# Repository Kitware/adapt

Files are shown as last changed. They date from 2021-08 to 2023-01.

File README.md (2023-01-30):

# ADAPT Multi-Mission Payload

### An open source platform for deploying state of the art deep-neural-network computer vision in real time on small unmanned aircraft systems (sUAS).

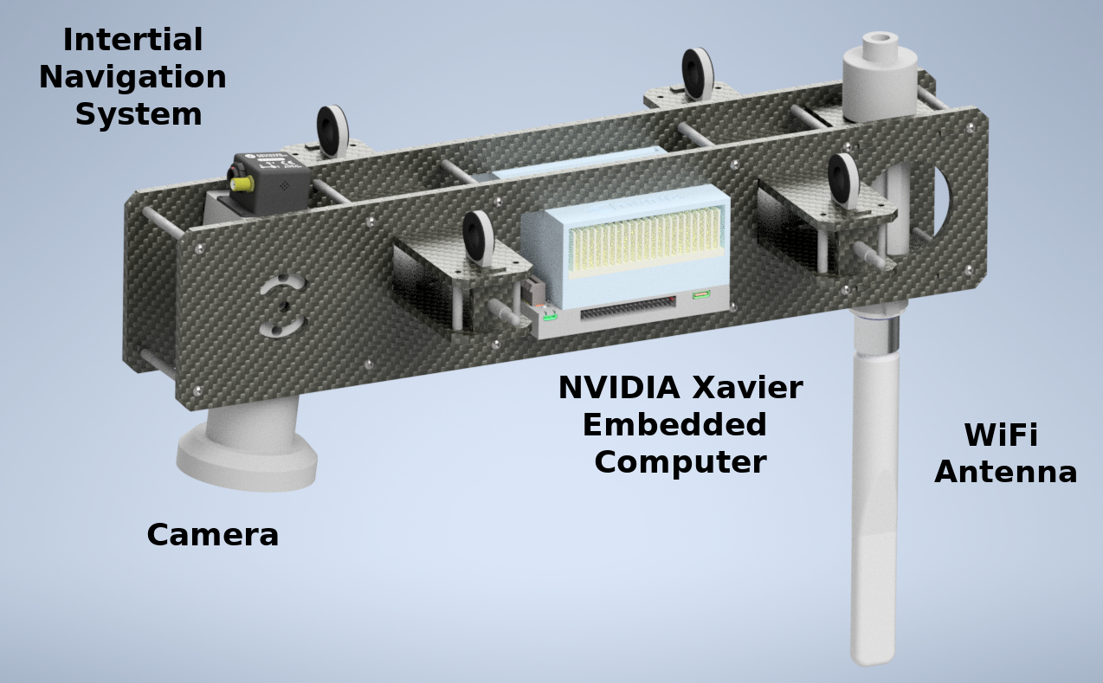
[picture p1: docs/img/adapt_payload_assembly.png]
Payload CAD Rendering

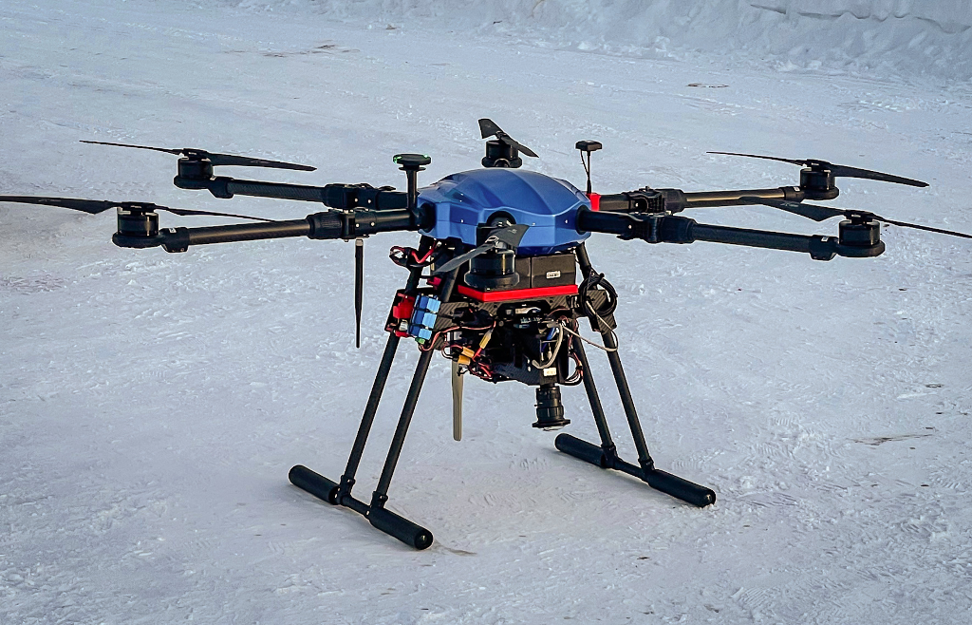
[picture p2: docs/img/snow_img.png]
sUAS


* Optimized drone-based collection of imagery and geospatial metadata with live feedback to maintain quality control.

* Integration with the open source do-it-yourself AI toolkit [VIAME](https://www.viametoolkit.org/) to annotate data and train mission-specific image-processing models.

* Upload your models for aerial deployment with real-time, georegistered analytics wirelessly transmitted to a ground station computer and beyond for rapid dissemination.

* Commodity [hardware components](https://kitware.github.io/adapt/parts), [CAD models](https://github.com/Kitware/adapt/tree/main/cad), and [open-source software](https://gitlab.kitware.com/adapt/adapt_ros_ws) allows organizations to cheaply and easily build their own payloads

## Supports a variety of unique missions

* [Sea and River Ice Monitoring](https://kitware.github.io/adapt/ice_monitor)
* [Monitoring Arctic Mammal Populations](https://kitware.github.io/adapt/ice_seal)
* [Person Search and Rescue](https://kitware.github.io/adapt/search_and_rescue)
* [Wild Fire Monitoring](https://kitware.github.io/adapt/fire_monitoring)
* [Coastline Erosion Monitoring](https://kitware.github.io/adapt/coastline_monitoring)

Ongoing work on the ADAPT project is funded by [NOAA](https://www.noaa.gov/) to support [key missions](https://uas.noaa.gov/Portals/5/Docs/NOAA%20UAS%20Program%20Overview%2019Apr2019.pdf?ver=2019-04-22-144716-137).

## Source Code
The ADAPT payload source code is hosted here: [https://gitlab.kitware.com/adapt/adapt_ros_ws](https://gitlab.kitware.com/adapt/adapt_ros_ws) or
[Try the simulator with docker](https://gitlab.kitware.com/adapt/adapt/-/tree/master/AirSim). Please use the Issue Tracker on Gitlab or contact us [here](https://kitware.github.io/adapt/contact/).

## License
This repository is under the Apache 2.0 license, see NOTICE and LICENSE file.

## Documentation
Documentation: [https://kitware.github.io/adapt/](https://kitware.github.io/adapt/)

## Events
* [Kitware and ACUASI September 2021 data collection in Fairbanks Alaska](https://kitware.github.io/adapt/sept_2021_collects).
* [The 3rd NOAA Workshop on Leveraging AI in Environmental Sciences](https://2021noaaaiworkshop.sched.com/info)

## Papers / Presentations
* (2022) National Innovation Center Seminar: [Slides](https://docs.google.com/presentation/d/1Z0FEdAjt3vTNZYKwsOXEP_GBd8f6RWV7H0KD1kT_Cfg/edit?usp=sharing)

* (2022) Ocean Sciences Meeting: [Slides](https://docs.google.com/presentation/d/15Ib9vKES6aAzlCuejUdRuDkyPnBcADa_OHr9GyepWBY/edit?usp=sharing)

* (2022) 1st International Workshop on Practical Deep Learning in the Wild at AAAI Conference on Artificial Intelligence: [Paper](https://arxiv.org/abs/2201.10366)

* (2021) NOAA Innovators Series: [Slides](https://docs.google.com/presentation/d/1Bp65DTJMgateIyRNzrCvjfHrLshqS3AUaba3lLGbTts/edit?usp=sharing), [Recording](https://www.youtube.com/watch?v=eD95Di6B5wo&t=1735s)
* (2021) The 3rd NOAA Workshop on Leveraging AI in Environmental Sciences: [Slides](https://docs.google.com/presentation/d/1PMgJrYxrqMtuJYR-xiAdFsjSSQt90_XOcYZ5pRXP4sk/edit#slide=id.p), [Recording](https://drive.google.com/file/d/1BI0qeIOw7TK262lNJzK_m3XIJd-RSvQn/view?usp=sharing)

## Site
For more information go to [https://kitware.github.io/adapt/](https://kitware.github.io/adapt/)

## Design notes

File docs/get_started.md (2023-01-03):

# Getting started with ADAPT

The ADAPT payload source code is hosted here: [https://gitlab.kitware.com/adapt/adapt_ros_ws](https://gitlab.kitware.com/adapt/adapt_ros_ws).

# Trying ADAPT without any hardware

There is also another way to explore the ADAPT processing software without requiring a flyable ADAPT payload here: [ADAPT Processing of AirSim Data](https://gitlab.kitware.com/adapt/adapt/-/tree/master/doc/airsim_docker.md). This tutorial uses [Microsoft AirSim](https://microsoft.github.io/AirSim/) as a drone sensor emulator running alongside ADAPT processes within a fully Dockerized environment. Camera images along with associated ground-truth depth and semantic segmentation images are rendered and saved to disk as you navigate a simulated drone with your keyboard through a forested mountain landscape. The pairing of raw imagery with ground truth allows training a semantic segmentation deep-neural-network model using ADAPT training tools. Finally, the trained model is deployed to process AirSim imagery in real time.

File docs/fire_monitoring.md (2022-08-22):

# Wildfire Front Monitoring

Integrating an infrared camera and training a deep-neural-network model to segment regions within an image where a fire has and has-not-yet reached, the payload can automatically detect and georegister the fire front. With real-time down-linking of these analytics, emergency services can maintain situational awareness.

More to come...

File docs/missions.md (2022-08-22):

# Example Missions

The ADAPT payload is a general-purpose tool for optimized data collection and aerial deployment of real-time deep-neural-network image processing. A variety of missions can be supported simply by training mission-specific image-processing models. Georegistered analytics are wirelessly transmitted to a ground station computer and beyond, supporting missions where timely dissemination of results is critical.

* [Sea and River Ice Monitoring](ice_monitor.md)
* [Monitoring Arctic Mammal Populations](ice_seal.md)
* [Person Search and Rescue](search_and_rescue.md)
* [Wildfire Monitoring](fire_monitoring.md)
* [Flood Monitoring](flood_monitoring.md)
* [Coastline Erosion Monitoring](coastline_monitoring.md)
* Oil Spill Monitoring

... and more to follow

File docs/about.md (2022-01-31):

# About the ADAPT Project
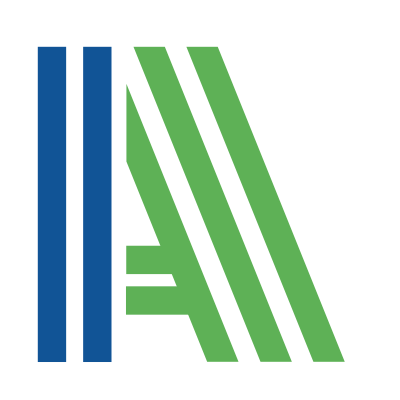
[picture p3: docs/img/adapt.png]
adapt logo
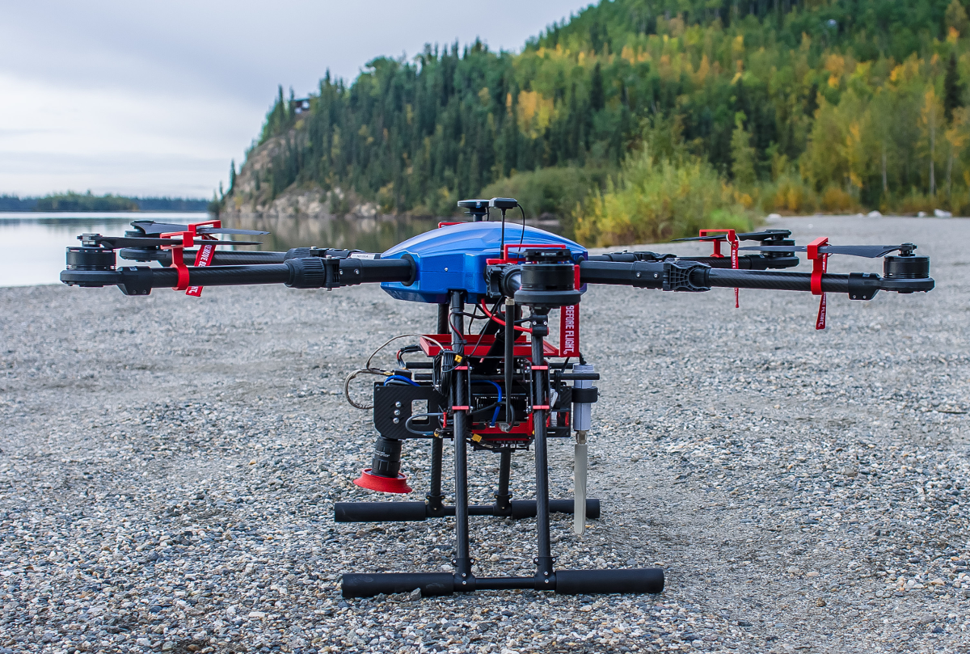
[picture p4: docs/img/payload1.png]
sUAS
 

**A**utonomous **D**ata **A**cquisition and **P**rocessing **T**echnologies

The ADAPT multi-mission payload is an open-source project started by [Kitware Inc.](https://www.kitware.com/), in collaboration with [ACUASI](https://acuasi.alaska.edu/). The ADAPT payload was conceived as the on-board data collection and processing counterpart to the desktop and web-based processing capabilities of [VIAME](https://www.viametoolkit.org/). VIAME is an open-source toolkit developed by Kitware placing tools for image and video annotation and deep-learning-based training into the hands of domain experts, such as biologists, ecologists, and meteorologists, without requiring a computer science or machine learning background. Full integration of ADAPT with VIAME provides researchers with a consistent ecosystem of tools spanning the entire life cycle of their data, allowing quicker deployment of more-complete data products for their customers. For more details on how VIAME-ADAPT integration can add value to NOAA missions, see these [case studies](missions.md).

# Funding

Content on this site was prepared by Kitware Inc. using Federal funds under award NA20OAR0210083 from the National Oceanic and Atmospheric Administration, U.S. Department of Commerce. The statements, findings, conclusions, and recommendations are those of the author(s) and do not necessarily reflect the views of the National Oceanic and Atmospheric Administration or the U.S. Department of Commerce.

# Project Objectives
The objective of the ADAPT project is to develop a lightweight, low-power sUAS payload to provide on-board, real-time, deep-learning-based computer vision processing to autonomously distill down high-volume data into compact analytics that can be immediately transmitted to decision makers. Further objectives of the ADAPT payload include:

* Autonomous data adjudication and sensor control (e.g., visible and infrared cameras, navigation sensors) for optimized data collection during beyond-line-of-sight missions
* Automatic geo-registration of results leveraging navigation-sensor data and computer vision processing
* Curation of collected data for rapid and streamlined integration into [VIAME](https://www.viametoolkit.org/) for do-it-yourself deep-neural-network (DNN) training
* Real-time, on-board deployment of VIAME-trained deep neural networks for object (e.g., animal) detection and tracking as well as image segmentation (e.g., land cover mapping) with boundary vectorization for transmission over low-bandwidth down-links
* Support open science with easy-to-use, open-source software that can be deployed on low-cost, readily-available processing hardware, such as [NVIDA's Jetson](https://developer.nvidia.com/buy-jetson) edge computers

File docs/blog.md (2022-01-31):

# 2022 January 24

Additional flights recorded

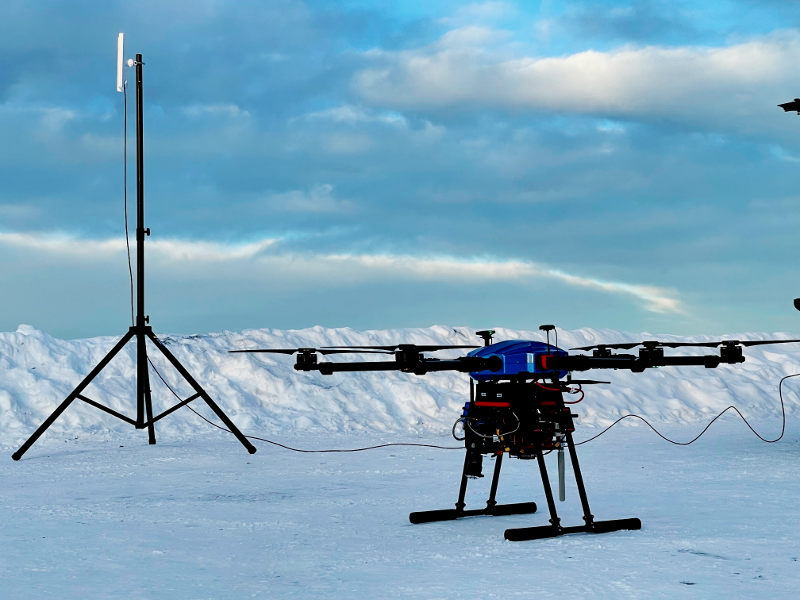
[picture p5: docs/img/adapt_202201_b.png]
payload on drone

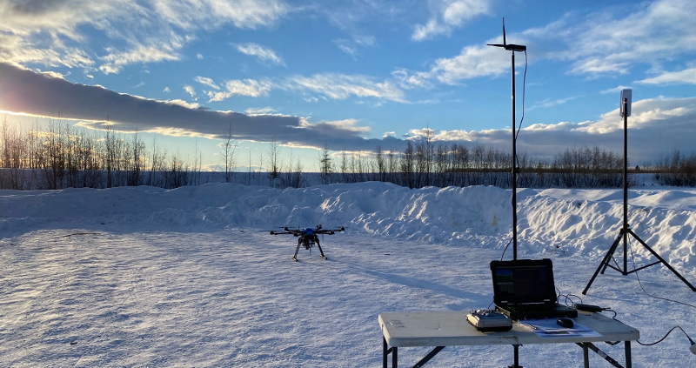
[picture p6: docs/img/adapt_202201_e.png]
base station

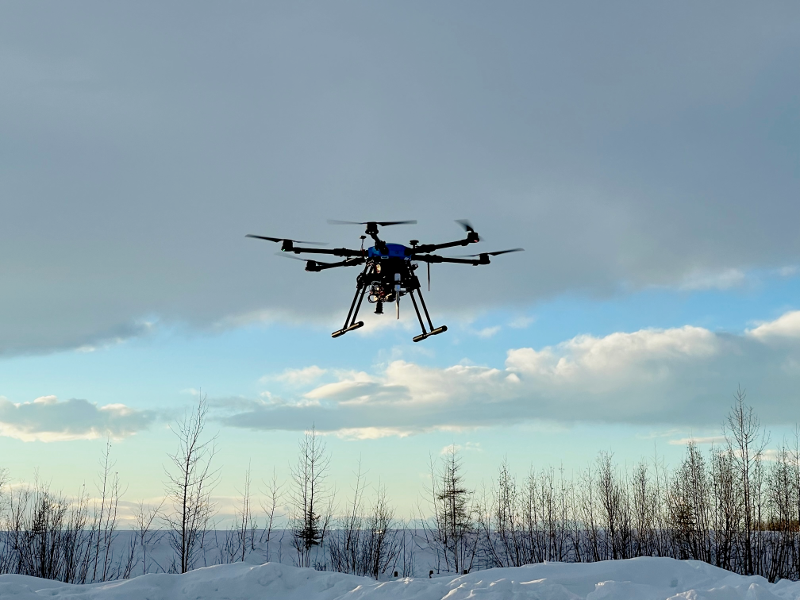
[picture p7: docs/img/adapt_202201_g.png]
payload flying


# 2021 November 4

Additional flights recorded

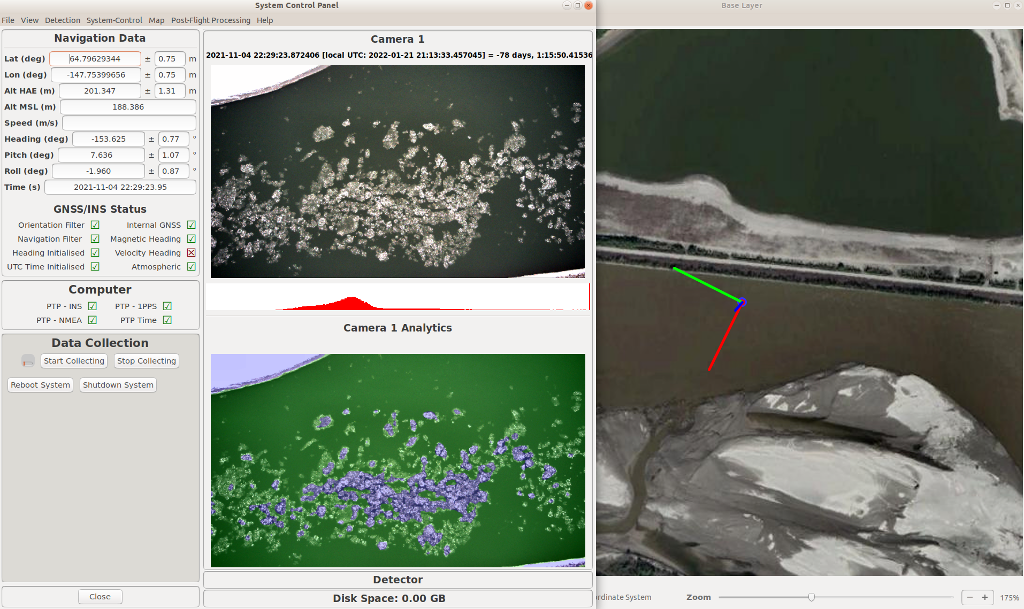
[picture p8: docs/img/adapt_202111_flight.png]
on screen image view with real time segmentation


# 2021 September 6-9

See our page on our [data collection in Fairbanks Alaska](sept_2021_collects.md).

# 2021 August 27

Payload testing on an UAS

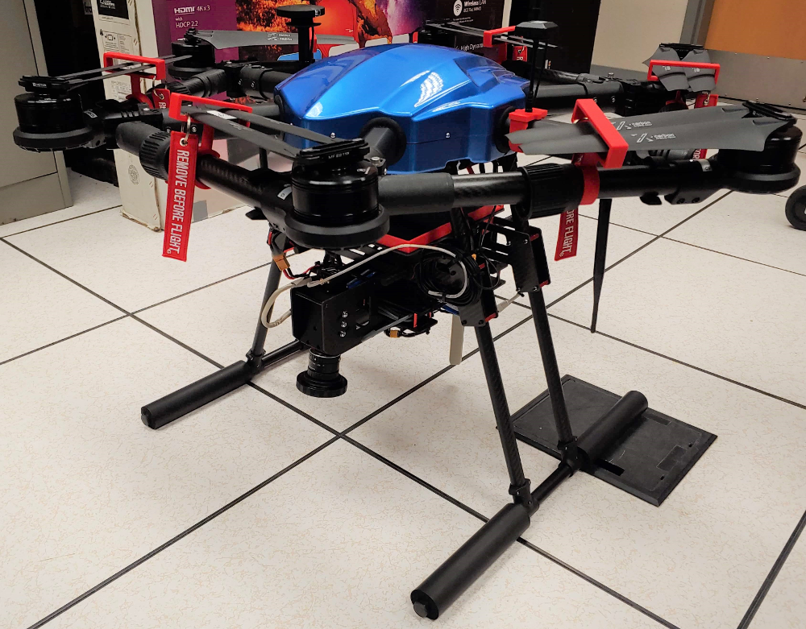
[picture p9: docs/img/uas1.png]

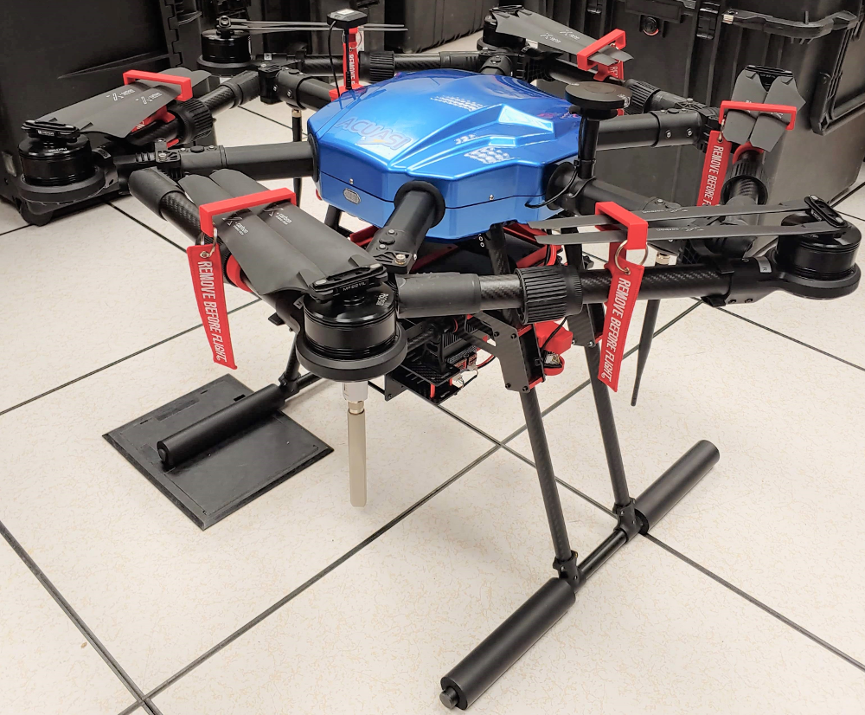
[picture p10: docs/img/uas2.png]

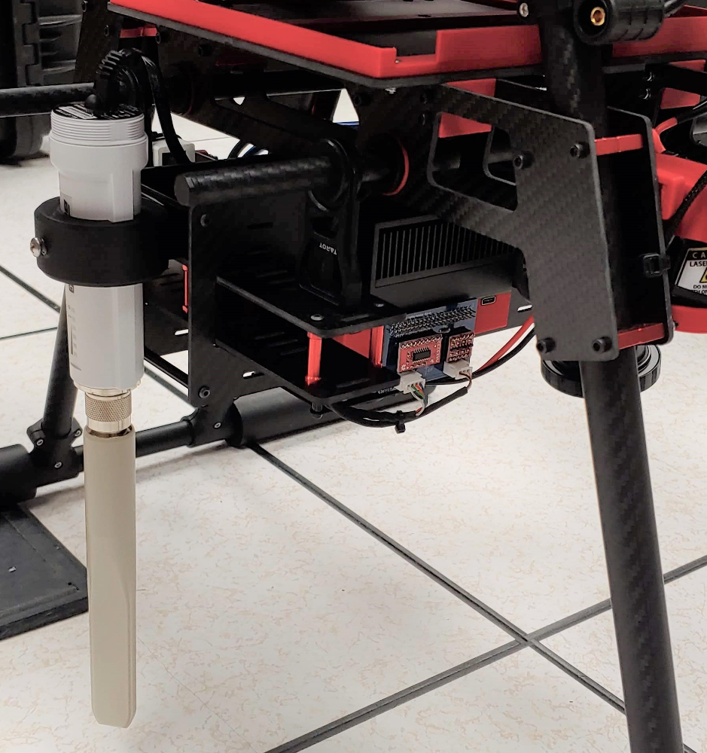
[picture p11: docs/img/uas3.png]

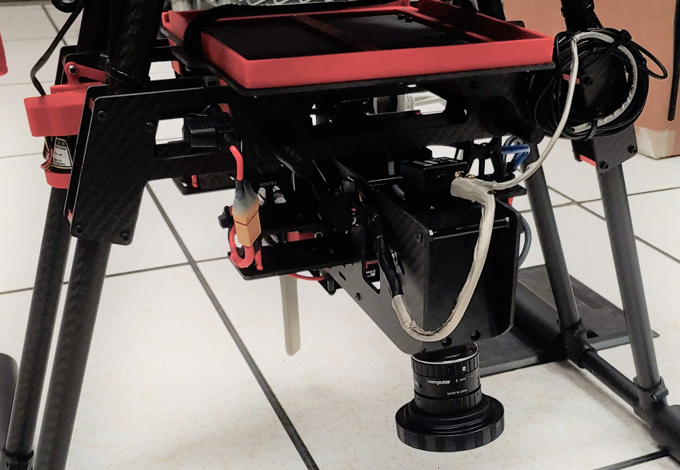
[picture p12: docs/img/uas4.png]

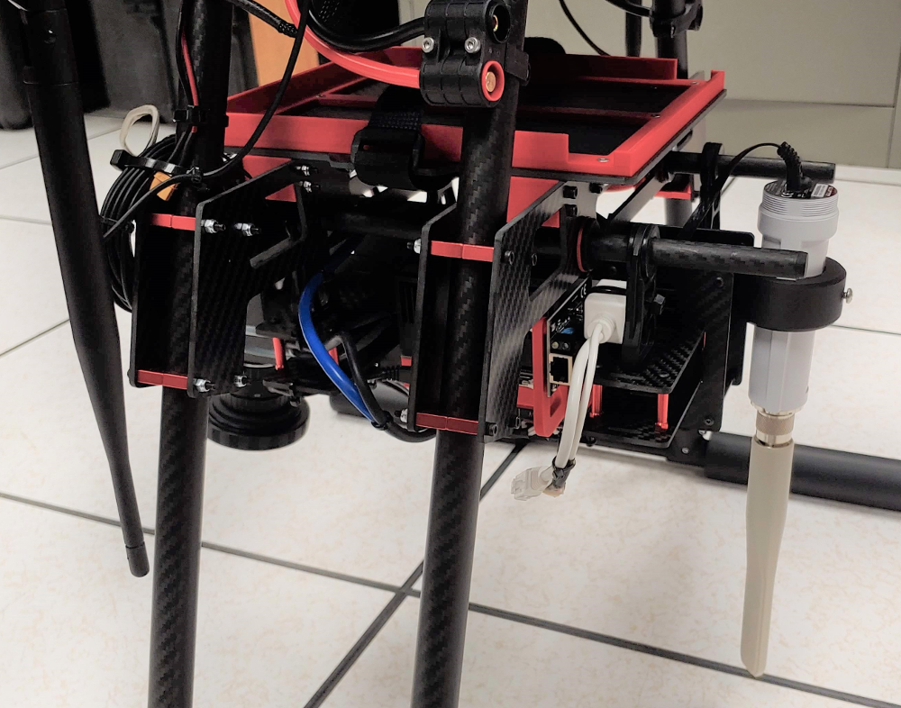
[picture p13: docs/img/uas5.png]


# 2021 August 11

Building the payload with all components in house
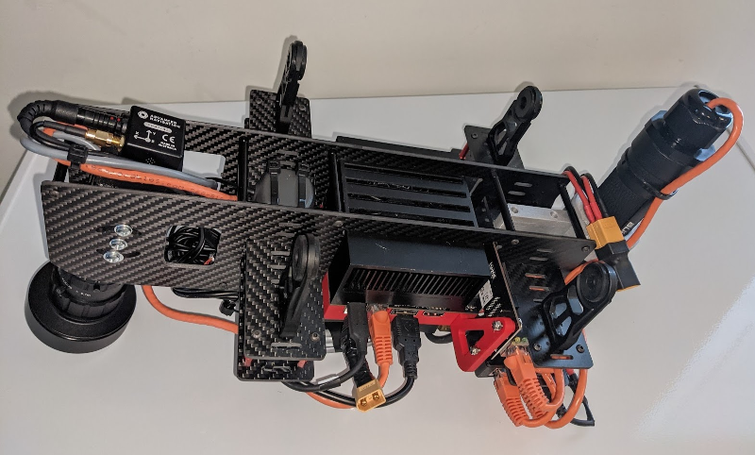
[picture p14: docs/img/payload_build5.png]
payload image 5

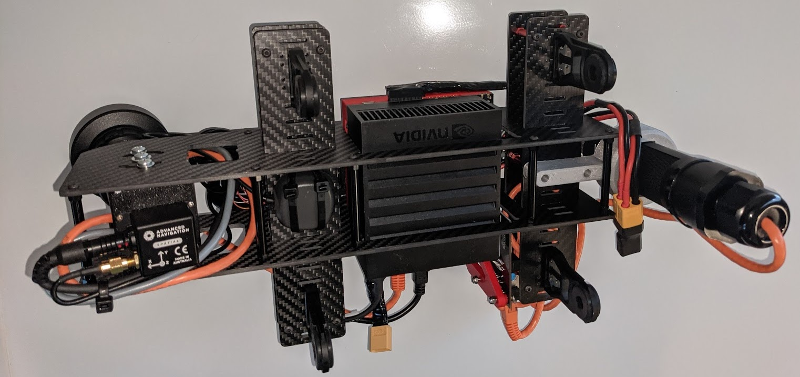
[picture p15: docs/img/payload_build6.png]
payload image 6

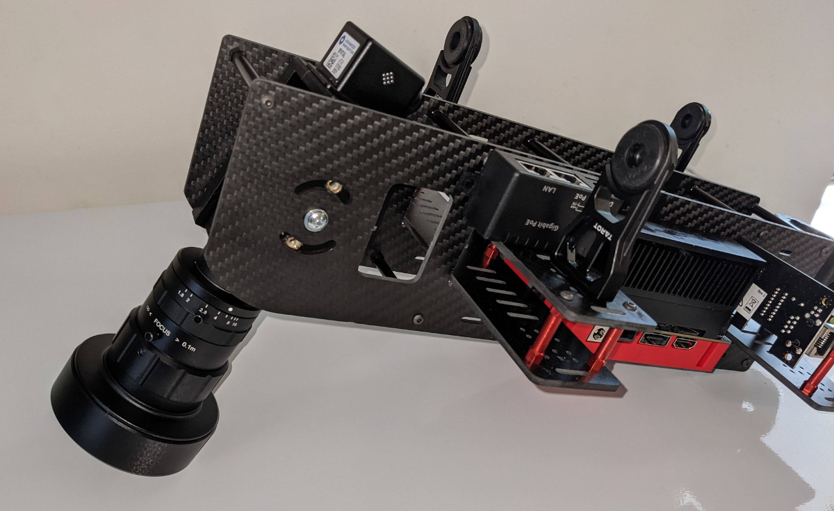
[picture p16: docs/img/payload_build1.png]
payload image 1

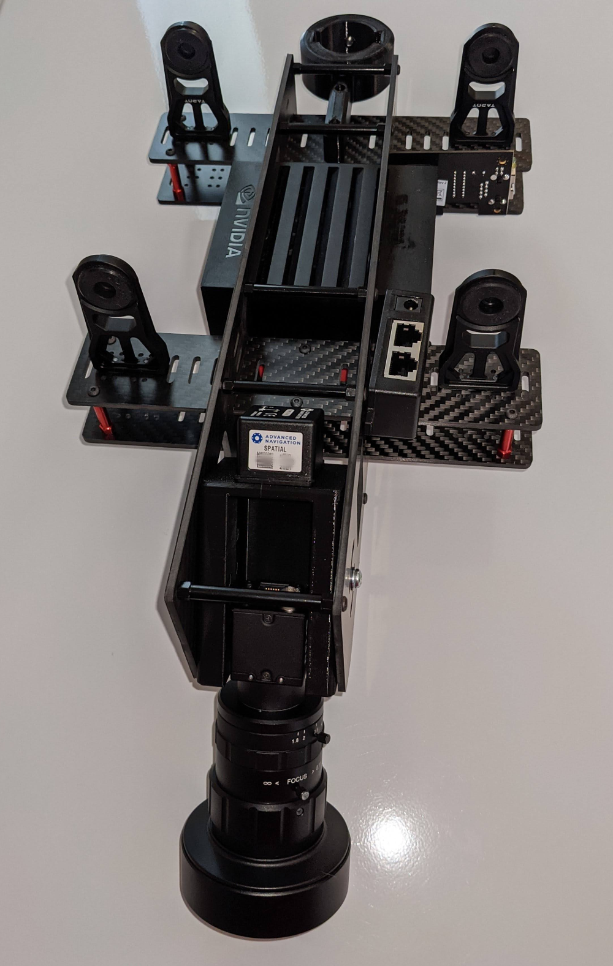
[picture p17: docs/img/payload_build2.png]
payload image 2

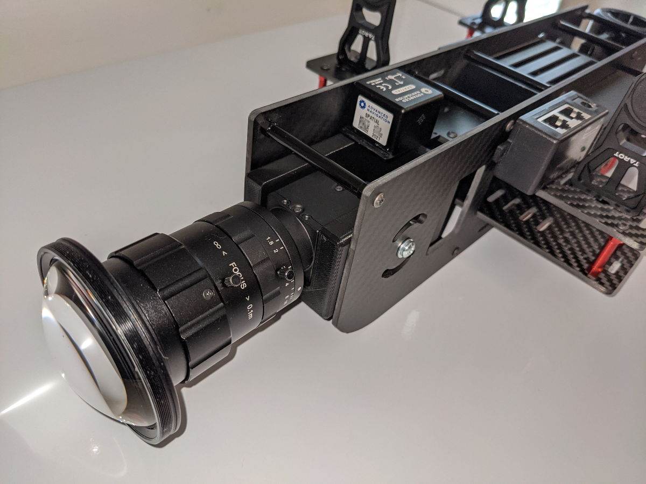
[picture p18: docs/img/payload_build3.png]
payload image 3

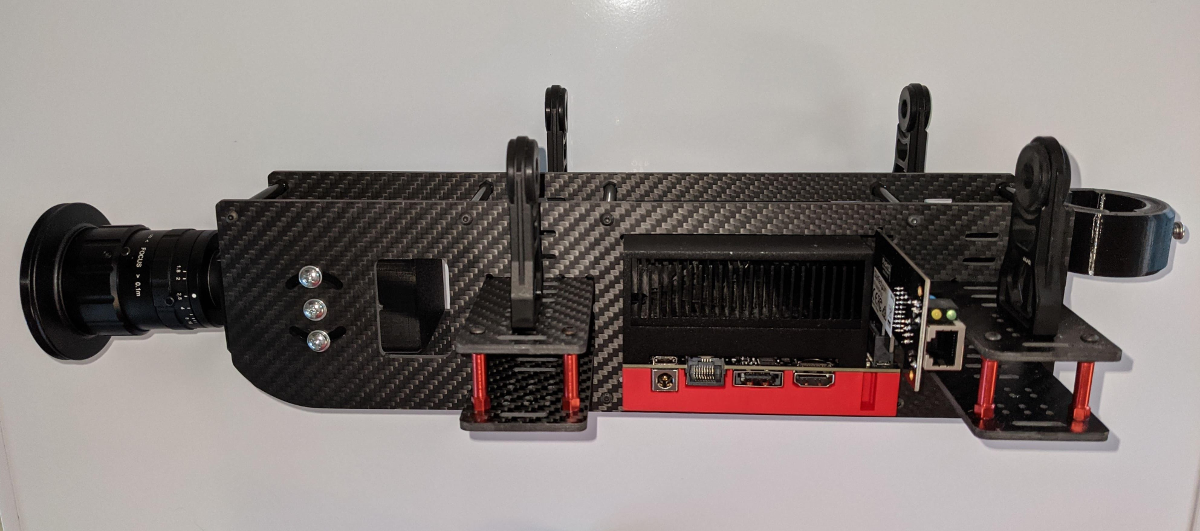
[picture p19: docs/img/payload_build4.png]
payload image 4


# 2021 July

The carbon fiber frame for the payload supports the 155mm standard rail for easy interfacing:

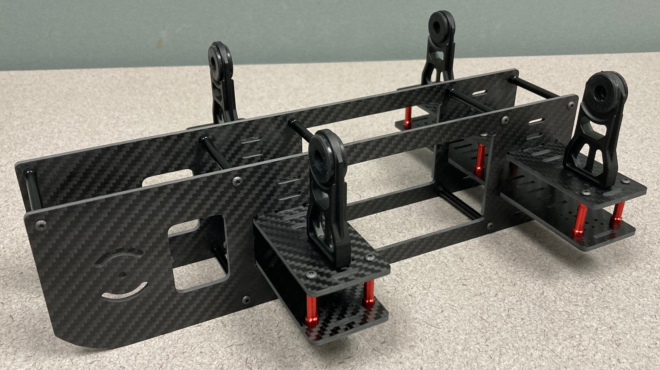
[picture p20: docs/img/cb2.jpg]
cb frame 1

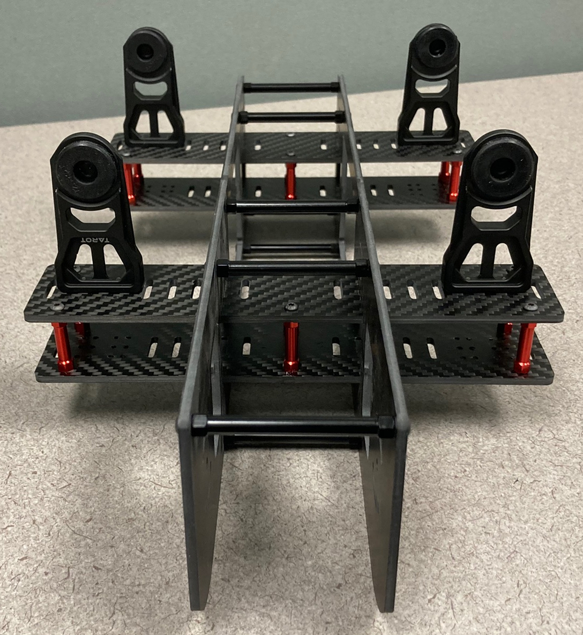
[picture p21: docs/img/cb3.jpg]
cb frame 2

*Above: Images of the assembled carbon fiber frame*

# 2021 June

Testing with a handheld version of the payload (not meant for flying)

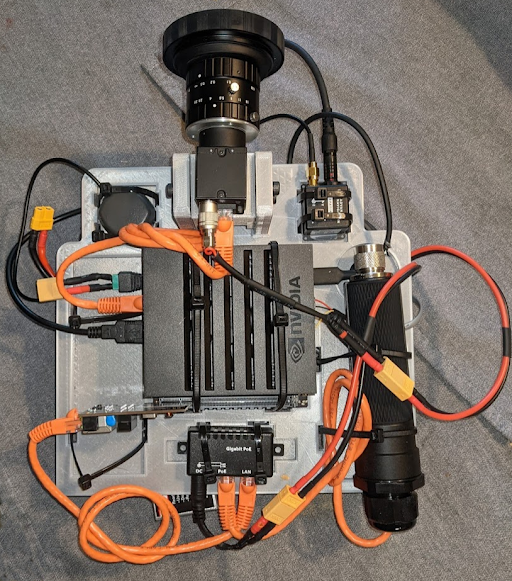
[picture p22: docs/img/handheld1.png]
handheld testing version


3D printed frame for fit testing

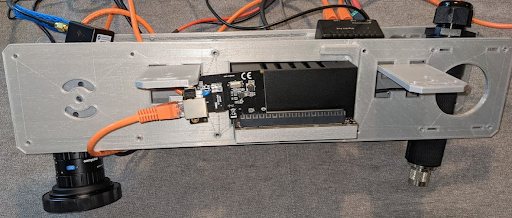
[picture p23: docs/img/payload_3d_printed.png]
3D printed payload frame


# 2020

Initial design concept for the payload:

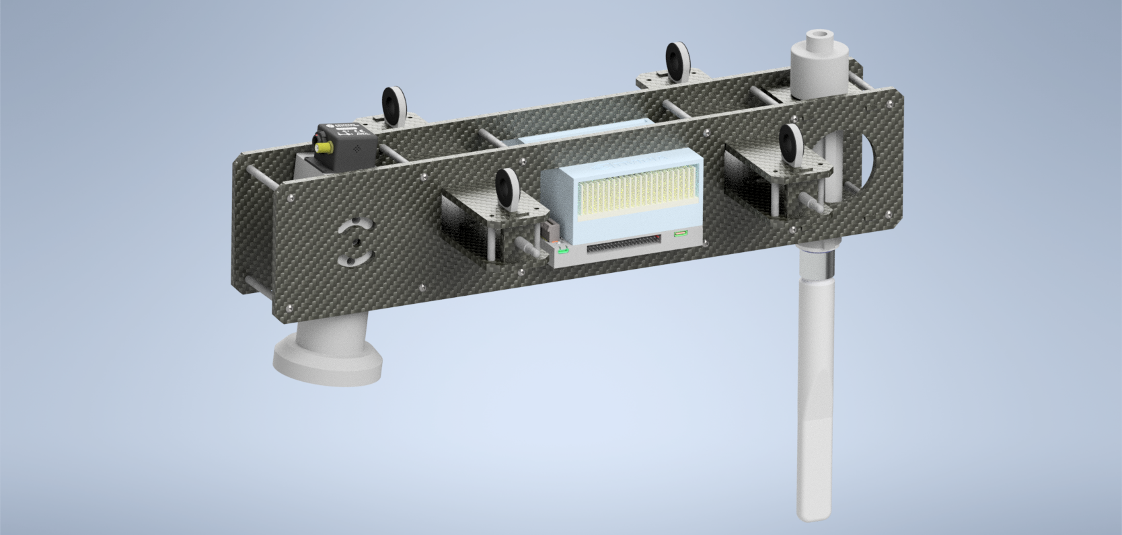
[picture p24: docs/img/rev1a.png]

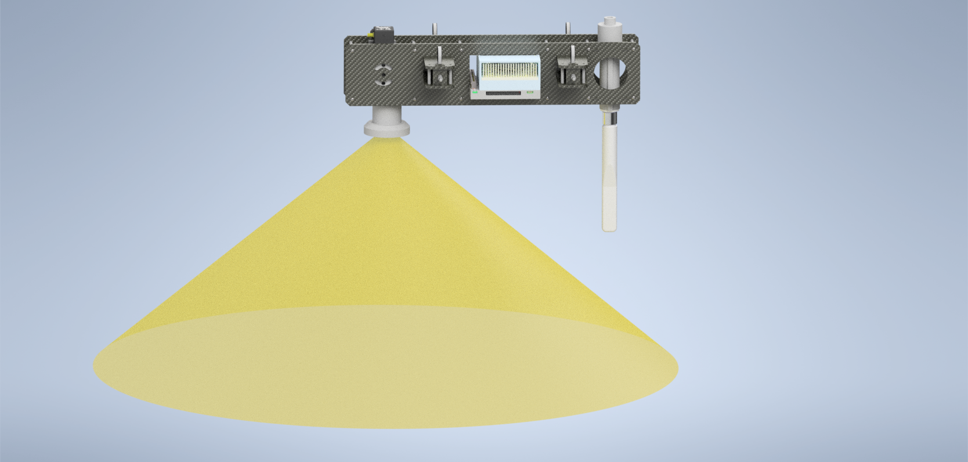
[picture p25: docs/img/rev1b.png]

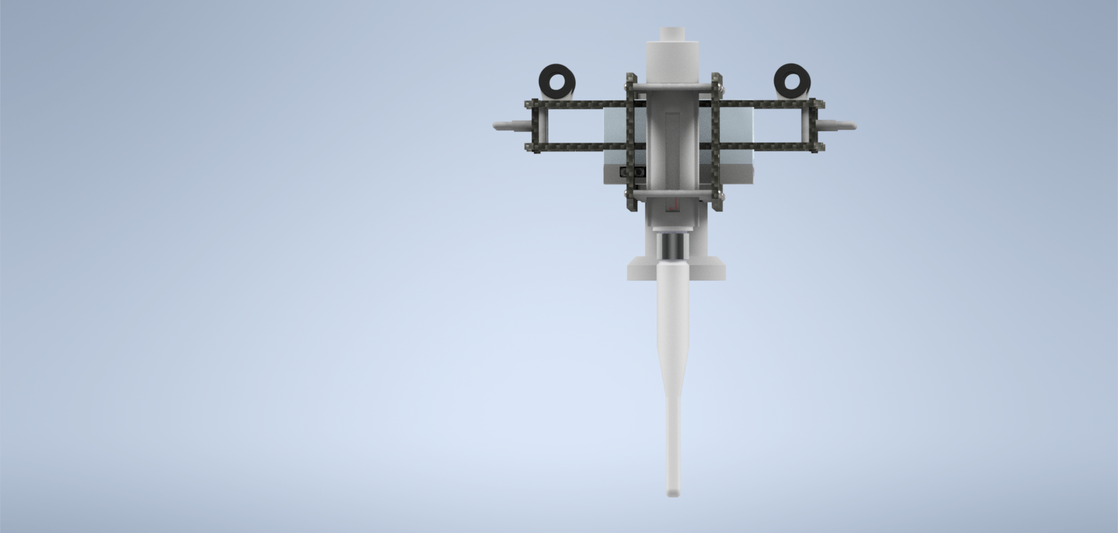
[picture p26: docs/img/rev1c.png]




*Above: Images of the design concept*

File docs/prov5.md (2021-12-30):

# Configuring automatic startup

[Back to Provisioning Overview](provisioning.md){.md-button}

The installation of the [ADAPT ROS Workspace](https://gitlab.kitware.com/adapt/adapt_ros_ws) contains a folder with example configuration files.  Among those are some systemd service files. NOTE: you may want to edit the paths inside the two files shown below to match where your 'adapt_ros_ws' files are located.

To install the systemd service files, follow these commands:
```
cd adapt_ros_ws/example_config/
sudo cp adapt_ptp_stack.service /etc/systemd/system/
sudo cp ros_stack.service /etc/systemd/system/
sudo systemctl daemon-reload
```

Now, when you reboot the two services should be running automatically. You can check on the status with these commands:
```
sudo systemctl status adapt_ptp_stack
sudo systemctl status ros_stack
```

In addition, you can connect to the services with tmux and observe/change any operations with these commands:
```
sudo tmux a -t adapt_live
sudo tmux a -t adapt_ptp
```

In the tmux window you can use these key cominations to move between windows, etc.:
```
# move to the next window:
# ctr-b n

# move to the previous window:
# ctrl-b p

# detach from session
# ctrl-b d
```

## Optional items: configure network addresses for ethernet devices

For the standard ADAPT software we are assuming the camera is on this network:
```
169.254.251.x
```
and the Wireless communications are on this network
```
100.0.0.x
```

[Back to Provisioning](provisioning.md){.md-button}

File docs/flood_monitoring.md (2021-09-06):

# Flood Front Monitoring

Integrating a color camera and training a deep-neural-network model to segment regions within an image where a flood has and has-not-yet reached, the payload can automatically detect and georegister the flood front. With real-time down-linking of these analytics, emergency services can maintain situational awareness.

More to come...

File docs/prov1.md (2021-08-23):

# Getting the ADAPT software stack

[Back to Provisioning Overview](provisioning.md){.md-button}

Below is a step-by-step explanation if you want to follow along or you can run this as a single script from [here](https://gitlab.kitware.com/adapt/adapt_ros_ws/-/blob/master/example_config/1_adapt_software.sh).

1. Install OS prerequisites:
```
sudo apt update
sudo apt install dirmngr gnupg2 python-catkin-tools python-pip python-tk python-rosdep python-rosinstall \
    python-vcstools ros-melodic-ros-core=1.4.1-0* ros-melodic-ros-base=1.4.1-0* ros-melodic-perception=1.4.1-0* \
    ros-melodic-rqt-image-view libgl1-mesa-glx libqt5x11extras5 gdal-bin python-gdal python-ujson \
    cuda-toolkit-10-2 cuda-core-10-2 libcudnn8-dev tensorrt tmux libhdf5-serial-dev hdf5-tools libhdf5-dev \
    zlib1g-dev zip libjpeg8-dev liblapack-dev libblas-dev gfortran gpsd chrony pps-tools linuxptp \
    nvidia-tensorrt python-libnvinfer-dev libopenblas-base libopenmpi-dev

```

2. Install python prerequisites:
```
# NOTE: install these dependencies as root so the systemd process can find them instead of a user account
sudo pip install anaconda ipython ipykernel matplotlib spyder-kernels protobuf \
    PyGeodesy shapely pyshp simplekml exifread future yacs scipy psutil pycuda
sudo pip install Pillow --upgrade
```

3. Get this version of pytorch for tegra from NVIDIA:
```
cd ~
wget https://nvidia.box.com/shared/static/yhlmaie35hu8jv2xzvtxsh0rrpcu97yj.whl -O torch-1.4.0-cp27-cp27mu-linux_aarch64.whl
sudo pip install future torch-1.4.0-cp27-cp27mu-linux_aarch64.whl
```

4. Setup torchvision
```
cd ~
git clone https://github.com/pytorch/vision
cd vision
git fetch origin v0.5.0
git reset --hard FETCH_HEAD
sudo python setup.py install
```

5. Setup a specific version of torch2trt:
```
cd ~
git clone https://github.com/NVIDIA-AI-IOT/torch2trt.git
cd torch2trt
git fetch origin b0cc8e77a0fbd61e96b971a66bbc11326f77c6b5
git reset --hard FETCH_HEAD
sudo python setup.py install --plugins
```

6. Run the rc_genicam_api install
```
cd ~
git clone https://github.com/roboception/rc_genicam_api.git
cd rc_genicam_api
mkdir build && cd build
cmake -DCMAKE_INSTALL_PREFIX=/usr ..
make && make package
sudo dpkg -i rc-genicam-api*.deb
```

7. Setup the adapt ros workspace
```
cd ~
git clone https://gitlab.kitware.com/adapt/adapt_ros_ws.git
cd adapt_ros_ws
git submodule init
git submodule update
catkin build --force-cmake -DSETUPTOOLS_DEB_LAYOUT=OFF
# get the model
cd ~/adapt_ros_ws/models
./get_sim_model.sh
```

## OPTIONAL items

Clean up some disk space:
```
sudo apt-get remove --purge libreoffice*
sudo apt-get autoclean
sudo apt-get autoremove
```

jtop for system stats:
```
pip install -U jetson-stats
# run jtop
```

jetsonUtilities:
```
git clone https://github.com/jetsonhacks/jetsonUtilities
cd jetsonUtilities
python jetsonInfo.py
```

[Next Step](prov2.md){.md-button}

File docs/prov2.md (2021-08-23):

# Setting up 1PPS hardware input

[Back to Provisioning Overview](provisioning.md){.md-button}

Setup the device tree overlay:
```
sudo nano /boot/pps.dts
# copy and paste the code below:
```
/boot/pps.dts
```
/dts-v1/;
/plugin/;

/ {
    overlay-name = "Jetson PPS";
    compatible = "p2822-0000+p2888-0001,p2972-0000-devkit,devboard";
    fragment {
        target-path = "/";
        __overlay__ {
                        pps: pps_gpio {
                                compatible = "pps-gpio";
                                gpios = <&tegra_main_gpio 56 1>;
                                status = "okay";
                        };
        };
    };
};
```

compile the dts:
```
cd /boot
sudo dtc -I dts -O dtb -@ -o pps.dtbo pps.dts

# it give may show some warnings:
# pps.dtbo: Warning (gpios_property): Property 'gpios', cell 1 is not a phandle reference in /fragment/#__overlay__/pps_gpio
# pps.dtbo: Warning (gpios_property): Could not get phandle node for /fragment/__overlay__/pps_gpio:gpios(cell 1)
```

Setup the overlay dtb file
```
sudo fdtoverlay -i tegra194-p2888-0001-p2822-0000.dtb -o tegra194-p2888-0001-p2822-0000-user-custom.dtb tegra194-p2888-0001-p2822-0000-hdr40.dtbo pps.dtbo
```

Edit the /boot/extlinux/extlinux.conf
```
sudo nano /boot/extlinux/extlinux.conf
# insert the new line between the INITRD and APPEND lines as shown below
```

/boot/extlinux/extlinux.conf
```
    LINUX ...
    INITRD ...
    FDT /boot/tegra194-p3668-all-p3509-0000-user-custom.dtb
    APPEND ...
```

Configure the hardware:
```
sudo /opt/nvidia/jetson-io/config-by-hardware.py -n "Jetson PPS"
# it should say:
# Configuration saved to /boot/tegra194-p2888-0001-p2822-0000-jetson-pps.dtb.
```

Now reboot and you should see a pps device with this command
```
ls /dev/ | grep pps
```
(that should show /dev/pps0)

Confirm that the signal is coming in:
```
dmesg --follow --ctime | grep capture
```
With that command issued you should see one message every second, similar to this:
```
[Mon May 31 09:50:54 2021] pps pps0: capture assert seq #2760932
[Mon May 31 09:50:55 2021] pps pps0: capture assert seq #2760933
[Mon May 31 09:50:56 2021] pps pps0: capture assert seq #2760934
[Mon May 31 09:50:57 2021] pps pps0: capture assert seq #2760935
[Mon May 31 09:50:58 2021] pps pps0: capture assert seq #2760936
```

[Next Step](prov3.md){.md-button}

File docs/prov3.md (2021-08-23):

# Configuring the time server

[Back to Provisioning Overview](provisioning.md){.md-button}

## Recommended (optional) steps: setting up the hardware device names

For the ADAPT payload software, we use /dev/gps and /dev/spatial as names for the NMEA and Advanced Navigation Spatial hardware names (this avoids issues with ttyUSB0/1/2 etc. numbering).  In order to set this up, you'll need to know the device IDs - usually found with the 'lsusb' command.  For reference, the USB hardware we used look like this:
```
lsusb
067b:2303 Prolific Technology, Inc. PL2303 Serial Port   # <- this is the 9-pin serial to USB converter
0403:6001 Future Technology Devices International, Ltd FT232 USB-Serial (UART) IC  # <- this is the standard Spatial USB cable
```
Setup the udev rule
```
sudo nano /etc/udev/rules.d/99-zgps.rules
# copy and paste the info below (after changing the IDs to match your hardware)
```
/etc/udev/rules.d/99-zgps.rules
```
SUBSYSTEM=="tty", ATTRS{idVendor}=="067b", ATTRS{idProduct}=="2303", GROUP="dialout",  SYMLINK+="gps"
SUBSYSTEM=="tty", ATTRS{idVendor}=="0403", ATTRS{idProduct}=="6001", GROUP="dialout", SYMLINK+="spatial"
```
Reload the udev rules to see /dev/gps and /dev/spatial
```
udevadm control --reload-rules && udevadm trigger
```

## Required steps: configuring gpsd and chronyd

Disable the standard timesync
```
sudo systemctl stop systemd-timesyncd.service
sudo systemctl disable systemd-timesyncd.service
```
Disable standard gpsd startup since we may need to run it in debug mode
```
sudo systemctl stop gpsd
sudo systemctl disable gpsd
sudo systemctl stop gpsd.socket
sudo systemctl disable gpsd.socket
```
If you do need to run it in debug mode, issue these commands to test it and see output
```
sudo killall gpsd
sudo gpsd -D 5 -N -n -b /dev/gps /dev/pps0
```
note: the ADAPT payload software will start gpsd (refer to [this](https://gitlab.kitware.com/adapt/adapt_ros_ws/-/blob/master/run_scripts/ptp/10_gpsd.sh) for reference)

Configure chrony
```
sudo systemctl stop chronyd
sudo nano /etc/chrony/chrony.conf
# add/edit lines as shown below
```
/etc/chrony/chrony.conf
```
allow
# rtcsync  # note: turn this off to not use system clock
refclock SHM 0 refid GPS precision 1e-1 offset 0.045 noselect
refclock SHM 2 refid PPS precision 1e-7 prefer
```
Start chrony and review the sources
```
sudo systemctl start chronyd
chronyc sources
```
we want the PPS and GPS to show like this:
```
MS Name/IP address         Stratum Poll Reach LastRx Last sample
===============================================================================
#- GPS                           0   4   377    12  +3580us[+3580us] +/- 101ms
#* PPS                           0   4   377    10    -86ns[ -157ns] +/- 181ns
```
Note: the * next to PPS

[Next Step](prov4.md){.md-button}

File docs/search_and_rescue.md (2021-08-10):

By exploiting readily available deep-neural-network models for person detection, the ADAPT payload could be used to alert to the presence of a person within a search area, providing a view of the detected person back to the ground station.

More to come...

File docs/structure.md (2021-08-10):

# Structure of the ADAPT payload

At this phase of the project, we are focused on developing and refining one concrete implementation of the ADAPT payload and sensor stack with an emphasis on low-cost components, clear documentation, and tutorials so that the project is approachable and the system's utility becomes clear to a wider audience of potential users. Currently, support is focused on the [NVIDA Jetson](https://developer.nvidia.com/buy-jetson) Xavier and Nano edge computers
and the primary sensing package provided by the [Advanced Navigation Spatial GPS/INS](https://www.advancednavigation.com/products/spatial).

In support of the open-source nature of this project, we leverage the [Robot Operating System (ROS)](https://www.ros.org/). ROS provides a rich ecosystem of out-of-the-box capabilities for interfacing with a wide array of cameras and sensors as well as common autonomous-system processing.

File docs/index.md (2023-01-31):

# ADAPT Multi-Mission Payload

### An open source platform for deploying state of the art deep-neural-network computer vision in real time on small unmanned aircraft systems (sUAS).

Get the source code: [https://gitlab.kitware.com/adapt/adapt_ros_ws](https://gitlab.kitware.com/adapt/adapt_ros_ws)

Payload CAD Rendering sUAS

* Optimized drone-based collection of imagery and geospatial metadata with live feedback to maintain quality control.

* Integration with the open source do-it-yourself AI toolkit [VIAME](https://www.viametoolkit.org/) to annotate data and train mission-specific image-processing models.

* Upload your models for aerial deployment with real-time, georegistered analytics wirelessly transmitted to a ground station computer and beyond for rapid dissemination.

* Commodity [hardware components](parts), [CAD models](https://github.com/Kitware/adapt/tree/main/cad), and [open-source software](https://gitlab.kitware.com/adapt/adapt_ros_ws) allows organizations to cheaply and easily build their own payloads

Real-Time Ground-Station View of Remote Payload Operation
type:video

Real-Time Deep Neural Network Ice Segmentation
type:video
Frozen Water (Blue) vs. Background (Green)

## Supports a variety of unique missions

* [Sea and River Ice Monitoring](ice_monitor.md)
* [Monitoring Arctic Mammal Populations](ice_seal.md)
* [Person Search and Rescue](search_and_rescue.md)
* [Wild Fire Monitoring](fire_monitoring.md)
* [Coastline Erosion Monitoring](coastline_monitoring.md)

Ongoing work on the ADAPT project is funded by [NOAA](https://www.noaa.gov/) to support [key missions](https://uas.noaa.gov/Portals/5/Docs/NOAA%20UAS%20Program%20Overview%2019Apr2019.pdf?ver=2019-04-22-144716-137).

## Explore
The ADAPT payload source code is hosted here: [https://gitlab.kitware.com/adapt/adapt_ros_ws](https://gitlab.kitware.com/adapt/adapt_ros_ws) or
[try the simulator with docker](https://gitlab.kitware.com/adapt/adapt/-/tree/master/AirSim)

## Events
* [Kitware and ACUASI September 2021 data collection in Fairbanks Alaska](sept_2021_collects.md).
* [The 3rd NOAA Workshop on Leveraging AI in Environmental Sciences](https://2021noaaaiworkshop.sched.com/info)

## Papers / Presentations
* (2022) National Innovation Center Seminar: [Slides](https://docs.google.com/presentation/d/1Z0FEdAjt3vTNZYKwsOXEP_GBd8f6RWV7H0KD1kT_Cfg/edit?usp=sharing)

* (2022) Ocean Sciences Meeting: [Slides](https://docs.google.com/presentation/d/15Ib9vKES6aAzlCuejUdRuDkyPnBcADa_OHr9GyepWBY/edit?usp=sharing)

* (2022) 1st International Workshop on Practical Deep Learning in the Wild at AAAI Conference on Artificial Intelligence: [Paper](https://arxiv.org/abs/2201.10366)

* (2021) NOAA Innovators Series: [Slides](https://docs.google.com/presentation/d/1Bp65DTJMgateIyRNzrCvjfHrLshqS3AUaba3lLGbTts/edit?usp=sharing), [Recording](https://www.youtube.com/watch?v=eD95Di6B5wo&t=1735s)
* (2021) The 3rd NOAA Workshop on Leveraging AI in Environmental Sciences: [Slides](https://docs.google.com/presentation/d/1PMgJrYxrqMtuJYR-xiAdFsjSSQt90_XOcYZ5pRXP4sk/edit#slide=id.p), [Recording](https://drive.google.com/file/d/1BI0qeIOw7TK262lNJzK_m3XIJd-RSvQn/view?usp=sharing)

sUAS sUAS

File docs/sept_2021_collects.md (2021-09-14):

# September 2021 data collects in Alaska

[Kitware](https://www.kitware.com/url) and [ACUASI](https://acuasi.alaska.edu/) tested our payload at the [Tanana River](https://www.google.com/maps/place/64%C2%B047'47.1%22N+147%C2%B044'52.6%22W/@64.7964167,-147.75002,351m/data=!3m2!1e3!4b1!4m5!3m4!1s0x0:0x0!8m2!3d64.7964127!4d-147.7479326) and the [Chena River](https://www.google.com/maps/place/64%C2%B047'40.9%22N+147%C2%B057'10.0%22W/@64.7947066,-147.954961,370m/data=!3m2!1e3!4b1!4m5!3m4!1s0x0:0x0!8m2!3d64.7947043!4d-147.952767). These flights were focused on making sure the payload hardware and software are fully functional and support real-time deep-neural-network procession. After we analyze the data that we have collected, we will make it available for public access.

payload in drone at Fairbanks
payload in drone at Fairbanks
payload in drone at Fairbanks

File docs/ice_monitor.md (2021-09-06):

# River Ice Monitoring and Flood Prediction

With the onset of spring in Alaska, the winter snowpack melts and drains into its streams and rivers. If this snowmelt is rapid and the river ice is still mostly intact, dramatic mechanical breakup can occur, leading to downsream flooding. Such an event occured in 2013 along the Yukon River, leading to devastating floods in Galena, Alaska. High water and ice hit many villages along the river. Colossal damage left a heavy economic toll with 169 houses destroyed and an estimated $6 million needed to rebuild the public infrastructure. Historically, breakup-flood forecasting relies on manned aerial reconnaissance flights to issue timely flood watches and warnings. These flights provide observations to track river ice conditions (strength, extent, and movement) over large regions (tens to hundreds of miles) and identify ice jams.  The vast extent of Alaska, with limited ground observations, makes it difficult to provide timely and accurate forecasts. This leads to an overreliance on satellite-derived products, which are infrequently updated due to fixed observation windows limited by orbital period, low spatial resolution, and high cost.

ADAPT Workflow

The ADAPT payload can be used for low-latency monitoring of changes in sea and river ice formations. Domain experts can use VIAME tools to annotate ADAPT-collected imagery to indicate the segmentation boundaries between land, ice, and water. VIAME can further be used to train a DNN semantic segmentation model that can reproduce these segmentations and classifications on yet-unseen data. The model is uploaded onto to the ADAPT payload to support in-flight extraction of dense segmentation maps of sea and river ice for each aquired image. ADAPT-system processing then distills these dense maps into a geo-registered, vectorized representations of the boundaries, which can be transmitted over a low-bandwidth downlink for real-time situational awareness for decision makers.

segmentation slider

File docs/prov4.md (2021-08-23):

# Setting up the PTP server

[Back to Provisioning Overview](provisioning.md){.md-button}

[Precision Time Protocol (PTP)](https://en.wikipedia.org/wiki/Precision_Time_Protocol) is used to synchronise clocks throughout a network. The ADAPT payload uses this technology because it can achieve accuracy at the sub-microsecond range. The cameras in use on the ADAPT payload accept PTP (IEEE 1588) packets to ensure the images have extremely accurate time stamps.

configure ptp4l
```
sudo systemctl stop ptp4l
sudo nano /etc/linuxptp/ptp4l.conf
# add/edit the lines below
```
/etc/linuxptp/ptp4l.conf
```
tx_timestamp_timeout    10
```
Start ptp4l and review status
```
sudo systemctl start ptp4l
sudo systemctl status ptp4l
```

We would expect to see something similar to the output shown below:
```
ptp4l[1642.768]: port 1: INITIALIZING to LISTENING on INITIALIZE
ptp4l[1642.768]: port 0: INITIALIZING to LISTENING on INITIALIZE
ptp4l[1642.769]: port 1: link up
ptp4l[1648.777]: port 1: LISTENING to MASTER on ANNOUNCE_RECEIPT_TIMEOUT_EXPIRES
ptp4l[1648.777]: selected best master clock 48b02d.fffe.3a7004
ptp4l[1648.777]: assuming the grand master role
```
Note: the "assuming grand master role" line.  This means we will be serving the time to the clients on the network.

[Next Step](prov5.md){.md-button}

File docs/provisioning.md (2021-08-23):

# Provisioning Guide

This guide walks a user through the steps of setting up software on the computer in order to have the ADAPT payload perform realtime analytics. Please note that some of the software used is subject to change and may need adjustments per platform. The guide is initially meant to work primarily on NVIDIA's Tegra hardware, but should represent steps that would be very similar, if not the same, on other hardware platforms.

## Simulation vs. Live Hardware

The guide below is meant to run on [live hardware](parts.md). If you would like to get started with a simulated setup, [start here](https://gitlab.kitware.com/adapt/adapt/-/tree/master/AirSim) instead.

## Initial flashing

Follow NVIDIA's [documentation on the initial flashing](https://docs.nvidia.com/jetson/l4t/){target=_blank}or start by using the [NVIDIA SDK Manager](https://developer.nvidia.com/nvidia-sdk-manager){target=_blank}.

## Installing ROS

The [Robot Operating System (ROS)](https://www.ros.org/) is used by the ADAPT payload for communications, logging, and more. Follow [these steps](http://wiki.ros.org/melodic/Installation/Ubuntu){target=_blank} to get ROS installed.

## Getting the ADAPT software stack

Follow [these steps](prov1.md) to setup prerequisite software and the open source ADAPT ROS software stack.

## Setting up 1PPS hardware input

The ADAPT payload uses a [One Pulse Per Second (1PPS)](https://en.wikipedia.org/wiki/Pulse-per-second_signal) input from the GPS sensor in order to synchronize the time on the system, sensors, and cameras as accurately as possible. Follow [these steps](prov2.md) to get 1PPS working.

## Configuring the time server

In order to make the ADAPT computer capable of serving time to the camera(s), [chrony](https://chrony.tuxfamily.org/) is used along with [gpsd](https://gpsd.gitlab.io/gpsd/). Follow [these steps](prov3.md) to get the time server setup.

## Setting up the PTP server

[Precision Time Protocol (PTP) or IEEE 1588](https://en.wikipedia.org/wiki/Precision_Time_Protocol) is a way to synchronize clocks throughout a network. Follow [these steps](prov4.md) to get PTP setup.

## Configuring automatic startup

Follow [these steps](prov5.md) to get the PTP and ADAPT software stacks running automatically when the computer boots up.

## Setting up the Basestation User Interface

Steps to setup a docker container with a User Interface (UI) for remotely monitoring/controlling the ADAPT software can be found [here](https://gitlab.kitware.com/adapt/adapt_ros_ws/-/tree/master/basic_ui).

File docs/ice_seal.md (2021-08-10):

# Monitoring Arctic Mammal Populations
We can consider the case study of [ice seal research](https://www.fisheries.noaa.gov/alaska/marine-mammal-protection/ice-seal-research-alaska) to demonstrate how VIAME-ADAPT integration adds value to the research workflow:

1. The ADAPT graphical user interface (GUI) sets mission metadata and the geospatial regions where data will be collected.
The ADAPT payload is flown on a sUAS, controlling camera settings and synchrozing exposures with intertial navigation system (INS) measurements, to collect images of ice seals. The coherent collection of imagery with INS measurenents along with computer vision processing allows geo-registration of the imagery.
2. After the mission, collected data is automatically uploaded to another computer or data curation server once internet access is available.
3. A biologist uses VIAME's web-based annotation tools to indicate each occurance of a seal in the collected imagery along with providing a classiciations for size and species.
4. These annotations are passed to VIAME's deep-neural-network object-detector training tools to train a model to detect and classify seals within imagery. Due to the geo-registration provided by the ADAPT collection, seal size in meters can be inferred to more-accurately classify seal age and reduce false alarms.
5. The VIAME-trained model is uploaded onto the ADAPT payload, allowing seals to be detected in-flight during the next mission. Images that the detector deems sufficiently unlikely to contain any seals are autonomously removed according to user-specified policies to allow longer flights before saturating onboard storage. When subsequent acquired images overlap in their ground coverage, image-feature tracking is used to track and suppress redundant detections.
6. Once the sUAS returns to base, summary analytics (e.g., numbers and locations of detected seals, seal density per km<sup>2</sup>) are immediately downloaded to help plan ensuing missions.
7. To further refine the accuracy of the seal-detection model, biologists adjudicate selected detections as true or false positives as well as annotate additional imagery where false negatives may be present, looping back to step 4.

ADAPT Workflow

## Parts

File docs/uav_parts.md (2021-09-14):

#  UAV Bill of Materials

!!! note "Work In Progress"
    This list is in progress and will be updated soon.

* Frame ($1,022):
    [EFT E610S L](https://www.aliexpress.com/item/4001178158274.html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,searchweb201602_,searchweb201603_)

* Motors ($1,530):
    [P-60X](https://store.tmotor.com/goods.php?id=804)

* Flight Controller + GPS + Telemetry ($543):
    [Pixhawk bundle](https://irlock.com/products/combo-cube-orange-ads-b-w-here3-rfd900-telemetry-set?_pos=9&_sid=382dabc7f&_ss=r)

* Radio controller ($229):
    [Taranis X9D+](https://www.amazon.com/FrSky-Taranis-Access-Telemetry-Silver/dp/B08JGBRB39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)

* Radio reciever ($36):
    [Taranis D8 RX](https://www.ebay.com/itm/222054146731?chn=ps&mkevt=1&mkcid=28)

* Laser range finder ($279):
    [Lightware SF11-C](https://www.robotshop.com/en/lightware-sf11-c-laser-rangefinder-120m.html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)

* Power adapter for payload ($351):
    [Mauch Power-Cube 4 V3](https://www.mauch-electronic.com/apps/webstore/products/show/7595441)
    - (note: set this up for 12V on 3 outputs)

* 2x Current sensor ($87):
    [Mauch current sensor](https://irlock.com/collections/mauch-electronics/products/mauch-004-pl-200-sensor-board-with-cfk-enclosure-8awg)

* Sensor hub ($42):
    [Mauch sensor hub](https://irlock.com/collections/mauch-electronics/products/mauch-010-pl-sensor-hub-x2-v2-with-cfk-enclosure)

* Batteries ():
    []()

* Misc ($200):
    - [Carbon fiber nylon filament](https://www.3dxtech.com/product/carbonx-pa6-cf/)
    - wire
    - fasteners
    - banana plugs
    - carbon fiber for battery tray holder

Total components Cost: $4450 - $6200

!!! note "Open Hardware"
    CAD models for the 3D printed components will be coming soon to the [CAD repository](https://github.com/Kitware/adapt/tree/main/cad)

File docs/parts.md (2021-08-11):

#  Payload Bill of Materials

* Embedded Computer with GPU ($750 \*):
    [Nvidia Jetson Xavier AGX](https://developer.nvidia.com/embedded/jetson-agx-xavier-developer-kit)
* Color Camera option 1 (global shutter):
    - Global shutter ($1750): [FLIR Blackfly S GigE BFS-PGE-161S7C-C](https://www.flir.com/products/blackfly-s-gige/?model=BFS-PGE-161S7C-C)
    - Lens ($1078): [Edmund Optics #86-569](https://www.edmundoptics.com/p/8mm-focal-length-hp-series-fixed-focal-length-lens/41693/)
* Color Camera option 2 (rolling shutter \*\*):
    - Rolling shutter ($780): [FLIR Blackfly S GigE BFS-PGE-200S6C-C](https://www.flir.com/products/blackfly-s-gige/?model=BFS-PGE-200S6C-C)
    - Lens ($550): [Computar V0826-MPZ](https://computar.com/product/1449/V0826-MPZ)
* Inertial Navigation System ($3230):
    [Advanced Navigation Spatial](https://www.advancednavigation.com/products/spatial)
* Wireless communications:
    - On payload ($182): [airMAX Bullet AC Dual-Band IP67 Radio](https://store.ui.com/collections/operator-airmax-devices/products/bullet-ac-ip67-1)
    - Antenna on payload ($15): [N-Type Dual Band](https://www.trendnet.com/products/wireless/5-7dBi-Outdoor-Dual-Band-Omni-Antenna-Kit-TEW-AO57)
    - Bridge at Base station ($80): [Ubiquiti LBE-5AC-GEN2-US LiteBeam Wireless](https://www.ui.com/airmax/litebeam-ac-gen2/)
* Other Required components:
    - M.2 NVMe SSD 1TB ($150): [Samsung 970 EVO](https://www.samsung.com/us/computing/memory-storage/solid-state-drives/ssd-970-evo-nvme-m-2-1tb-mz-v7e1t0bw/)
    - PoE injector for wireless ($8): [Passive single port injector](https://shop.poetexas.com/products/gpoe-1-wm)
    - PCIe Network card ($27): [STARTECH 1-PORT PCI EXPRSS GIGABIT](https://www.startech.com/en-us/networking-io/st1000spex2)
    - Cable for camera power ($67): [6-pin GPIO Hirose Connector](https://www.edmundoptics.com/p/blackflyreg-6-pin-gpio-hirose-connector-45m-cable/30350/)
    - Carbon fiber frame ($500): (Custom - Open Hardware CAD files to be uploaded)
* Misc:
    - Antenna adapter ($5): N Female to N Female
    - Level converter ($18): [Bi-Directional Level converter](https://www.sparkfun.com/products/12009)
    - (Mounting hardware)
    - (RJ45 Network cables)
    - (Misc. wiring and connectors)
    - (Misc. frame mounts, stand-offs, misc screws)

Total components Cost: $6574 - $8060

!!! note "Open Hardware"
    We will be updating this soon. In the spirit of Open Hardware, all the hardware components were selected from off-the-shelf components.

\* Approximate cost at time of purchase - some prices may vary (prices in USD including taxes and shipping)

\*\* The rolling shutter version of the camera is a cheaper option. However, it is not recommended if you intend to exploit the imagery for structure from motion (e.g., [TeleSculptor](https://telesculptor.org/)).

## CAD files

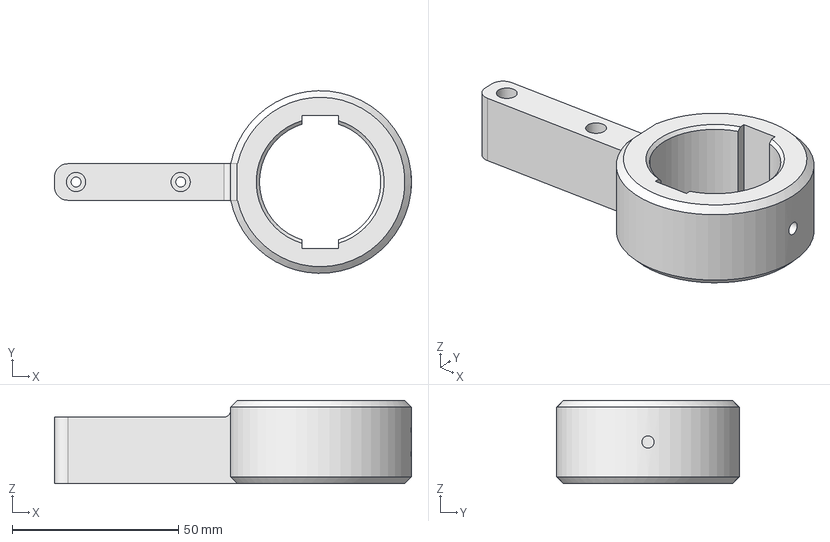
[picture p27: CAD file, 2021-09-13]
cad/adapt_bullet_ip67_mount.FCStd
107.5 x 55.0 x 25.0 mm

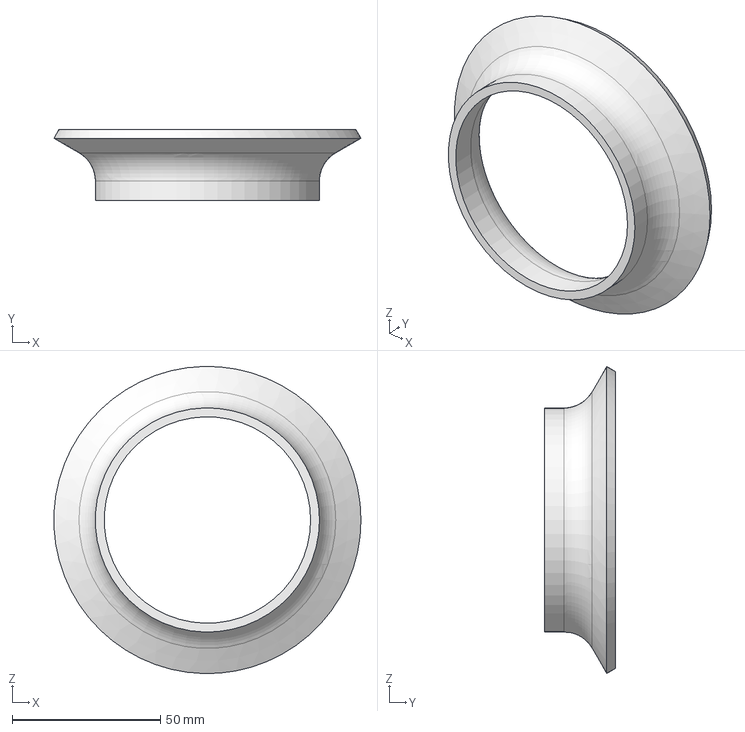
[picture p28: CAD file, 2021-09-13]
cad/adapt_lens_hood1.FCStd
103.4 x 24.0 x 103.4 mm

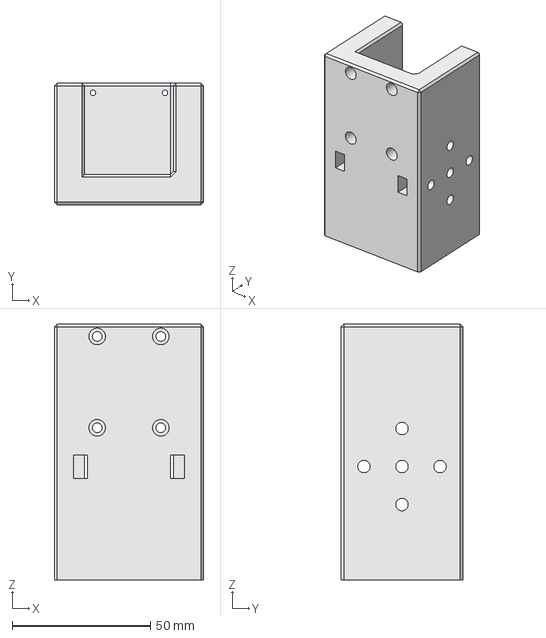
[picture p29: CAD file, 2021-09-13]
cad/adapt_cameraLarger_ins_mount.FCStd
54.0 x 44.0 x 92.5 mm

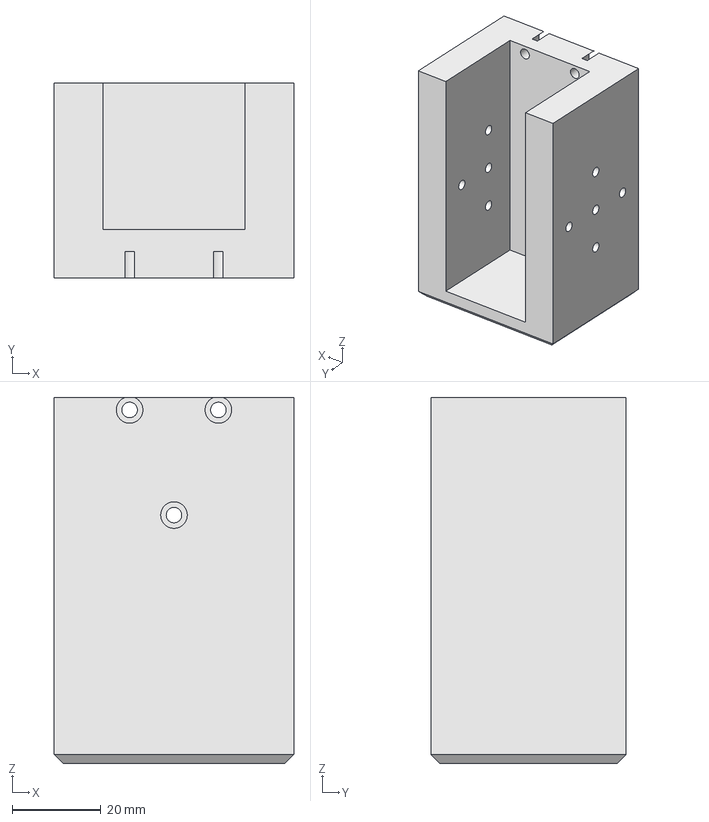
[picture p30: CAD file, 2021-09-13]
cad/adapt_camera_ins_mount.FCStd
54.0 x 44.0 x 82.5 mm

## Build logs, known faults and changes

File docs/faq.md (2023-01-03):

# Frequently Asked Questions

Have a question? Feel free to [contact us](https://kitware.github.io/adapt/contact/).

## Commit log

2021-09-13 add CAD files
    [adapt_bullet_ip67_mount.FCStd, adapt_cameraLarger_ins_mount.FCStd, adapt_camera_ins_mount.FCStd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]
2022-01-25 add CAD model file 20210916_A1001-1.zip
